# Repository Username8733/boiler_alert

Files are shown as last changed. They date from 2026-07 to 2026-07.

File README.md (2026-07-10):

# ESPHome Boiler Monitor






An ESPHome-based optical alarm monitor for boilers and other equipment with a visible warning LED.

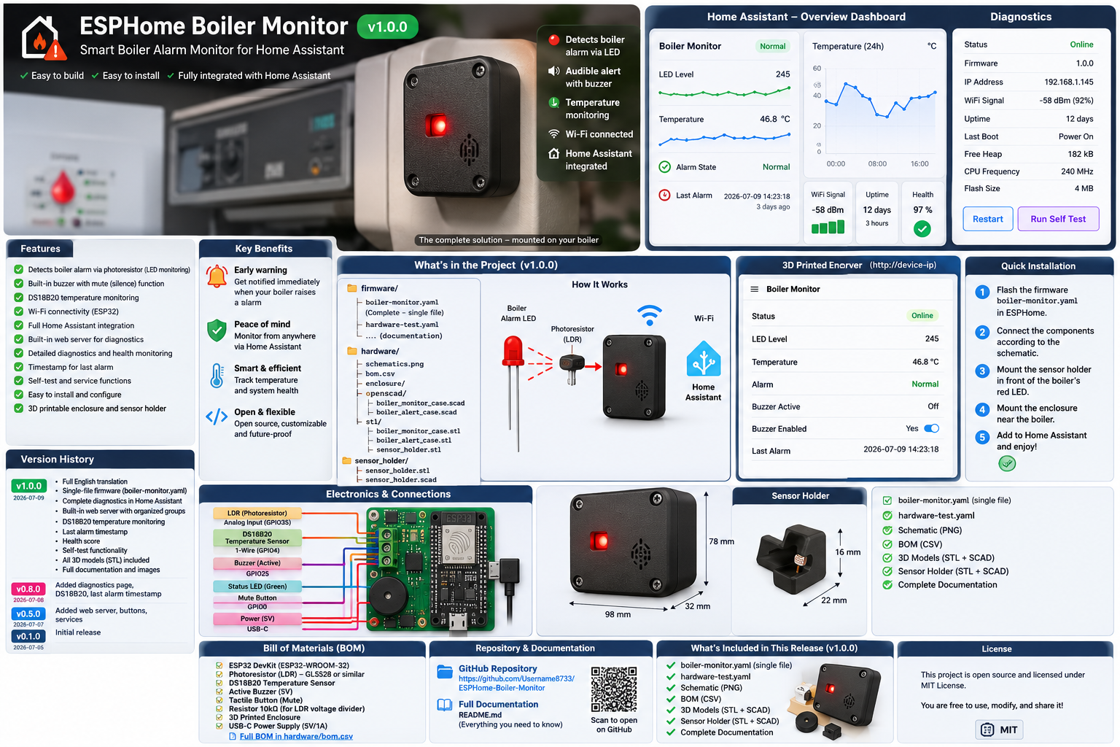
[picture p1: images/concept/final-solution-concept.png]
Final solution concept


## Features

- Optical alarm detection using a phototransistor
- Adjustable threshold
- Local red alarm LED
- Green status LED
- Active 5 V buzzer through a 2N7000 MOSFET
- Physical mute button
- DS18B20 temperature sensor support
- Last-alarm timestamp
- Built-in ESPHome web interface
- Home Assistant overview and diagnostics dashboards
- Dedicated hardware-test firmware
- 3D-printable enclosure and sensor holder

## Repository structure

```text
firmware/
  boiler-monitor.yaml
  hardware-test.yaml
  secrets.yaml.example

hardware/
  bom/
  wiring/
  enclosure/
    stl/
    openscad/

docs/
  Installation.md
  Hardware-Test.md
  Calibration.md
  Diagnostics.md
  Enclosure.md
  Troubleshooting.md

homeassistant/
  overview.yaml
  diagnostics.yaml
  notifications.yaml

images/
  concept/
  functions/
```

## Quick start

1. Copy `firmware/secrets.yaml.example` values into your ESPHome `secrets.yaml`.
2. Flash `firmware/hardware-test.yaml`.
3. Verify the LEDs, buzzer, MOSFET driver, and button.
4. Build the remaining circuit using `hardware/wiring/CONNECTION_TABLE.md`.
5. Flash `firmware/boiler-monitor.yaml`.
6. Add the ESPHome device to Home Assistant.
7. Import the Home Assistant dashboard files.
8. Calibrate the optical sensor.

## GPIO mapping

| Function | GPIO |
|---|---:|
| Phototransistor analog input | GPIO34 |
| Buzzer MOSFET gate | GPIO18 |
| Red alarm LED | GPIO19 |
| Green status LED | GPIO21 |
| Mute button | GPIO22 |
| DS18B20 data | GPIO23 |

## Wiring illustrations

- [Power](images/functions/01_power.png)
- [Phototransistor sensor](images/functions/02_phototransistor_sensor.png)
- [Red alarm LED](images/functions/03_red_alarm_led.png)
- [Green status LED](images/functions/04_green_status_led.png)
- [2N7000 and buzzer](images/functions/05_mosfet_buzzer.png)
- [Mute button](images/functions/06_mute_button.png)
- [DS18B20](images/functions/07_ds18b20.png)

SVG source files are included next to the PNG images.

## Firmware

Use one of these files:

- `firmware/hardware-test.yaml` for initial hardware verification
- `firmware/boiler-monitor.yaml` for normal operation

Both are standalone ESPHome files.

## Home Assistant

- `homeassistant/overview.yaml`
- `homeassistant/diagnostics.yaml`
- `homeassistant/notifications.yaml`

When Home Assistant and the ESP32 are on different VLANs, add the ESPHome integration manually using the device IP address.

## 3D-printable files

STL and OpenSCAD files are included for:

- Boiler Alert case
- Boiler Monitor case
- Optical sensor holder

## Documentation

- [Installation](docs/Installation.md)
- [Hardware test](docs/Hardware-Test.md)
- [Calibration](docs/Calibration.md)
- [Diagnostics](docs/Diagnostics.md)
- [Enclosure](docs/Enclosure.md)
- [Troubleshooting](docs/Troubleshooting.md)

## External links

- [ESPHome](https://esphome.io/)
- [Home Assistant](https://www.home-assistant.io/)
- [ESPHome integration](https://www.home-assistant.io/integrations/esphome/)
- [Project repository](https://github.com/Username8733/ESPHome-Boiler-Monitor)

## Safety

This is a hobby monitoring accessory. It does not replace the boiler manufacturer's safety systems, alarms, inspections, or maintenance requirements.

## License

MIT. See [LICENSE](LICENSE).

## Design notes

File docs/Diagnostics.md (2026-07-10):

# Diagnostics

The built-in ESPHome web server and Home Assistant diagnostics page expose:

- Firmware version
- IP address, SSID, MAC address
- Wi-Fi RSSI and calculated percentage
- Uptime
- LED level and threshold
- Boiler LED detected
- Latched alarm
- Buzzer active, muted, and enabled
- DS18B20 temperature
- Last alarm timestamp
- Hardware test, buzzer test, and restart controls

When Home Assistant and the ESP32 are on different VLANs, add the ESPHome integration manually by IP address and allow TCP 6053.

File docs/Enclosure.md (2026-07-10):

# Enclosure and Sensor Holder

Included models:

- `boiler_alert_case.scad` / `.stl`
- `boiler_monitor_case.scad` / `.stl`
- `sensor_holder.scad` / `.stl`

Recommended print settings:

- Black PETG or PLA
- 0.2 mm layer height
- 20-40% infill
- Print the sensor holder in black to reduce ambient-light leakage

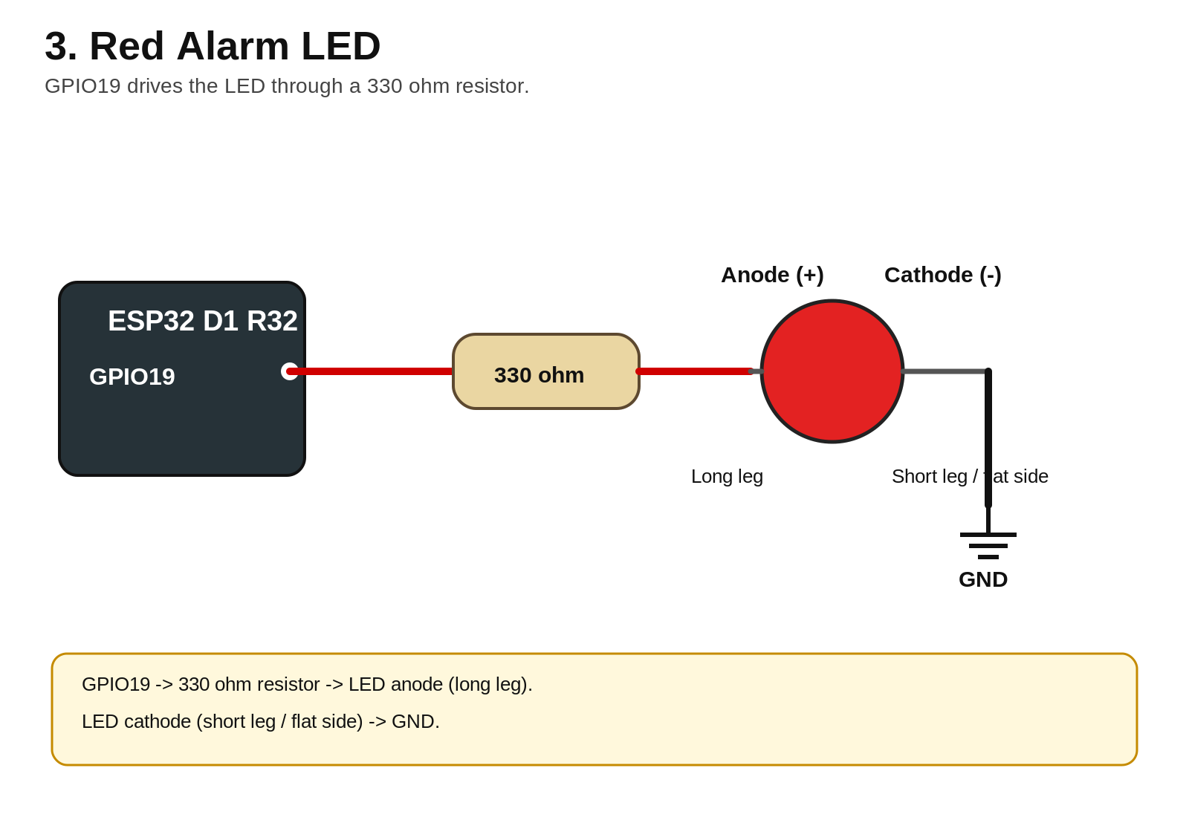
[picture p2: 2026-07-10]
images/functions/03_red_alarm_led.png

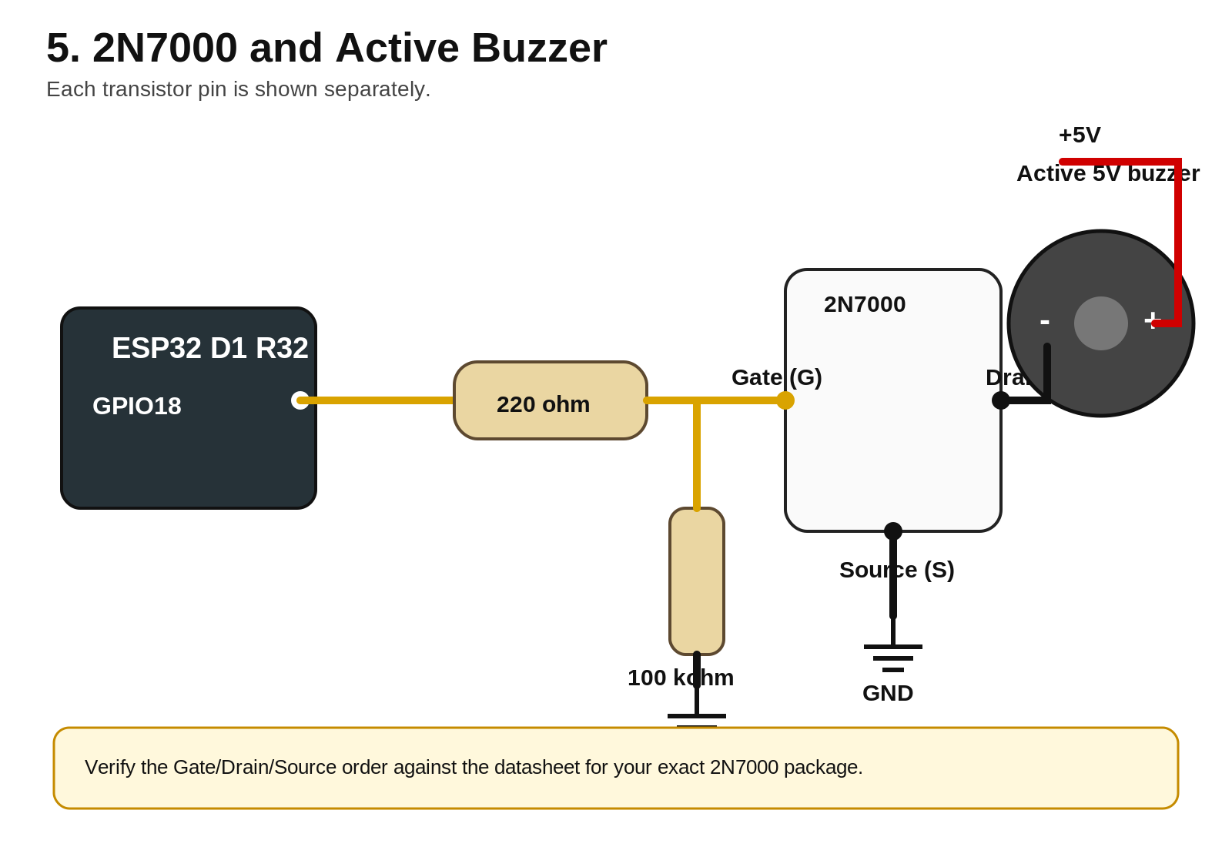
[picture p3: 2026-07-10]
images/functions/05_mosfet_buzzer.png

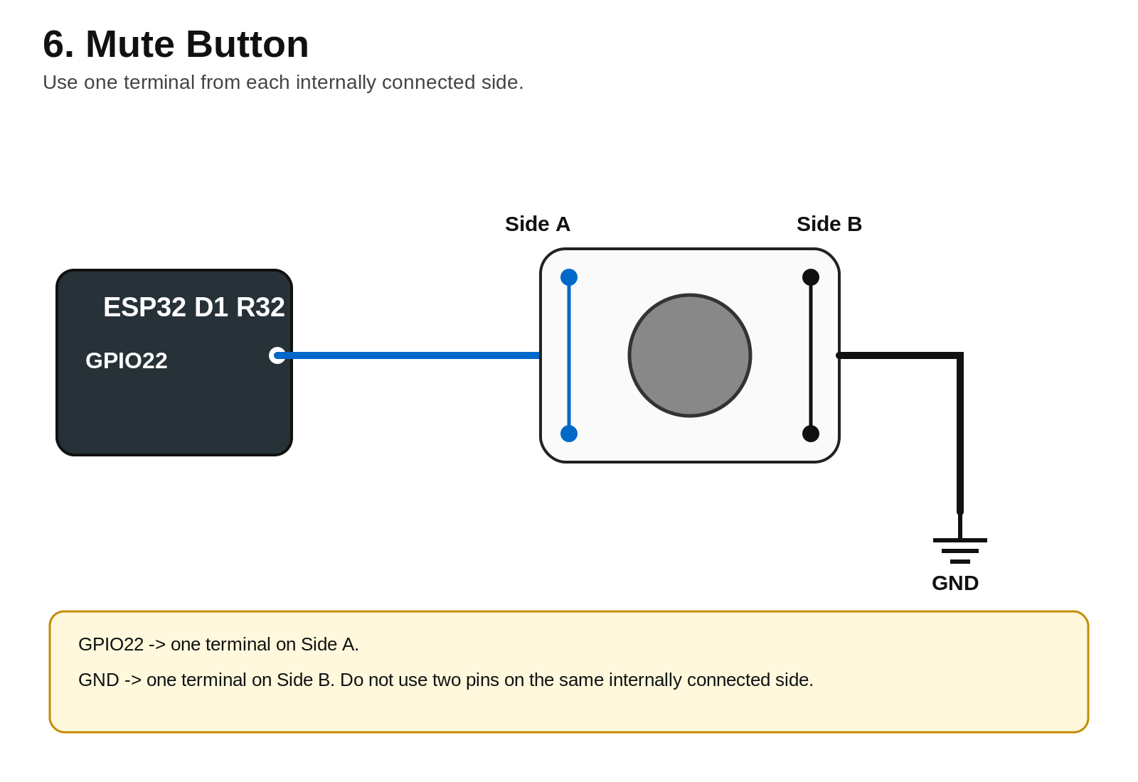
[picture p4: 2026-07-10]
images/functions/06_mute_button.png

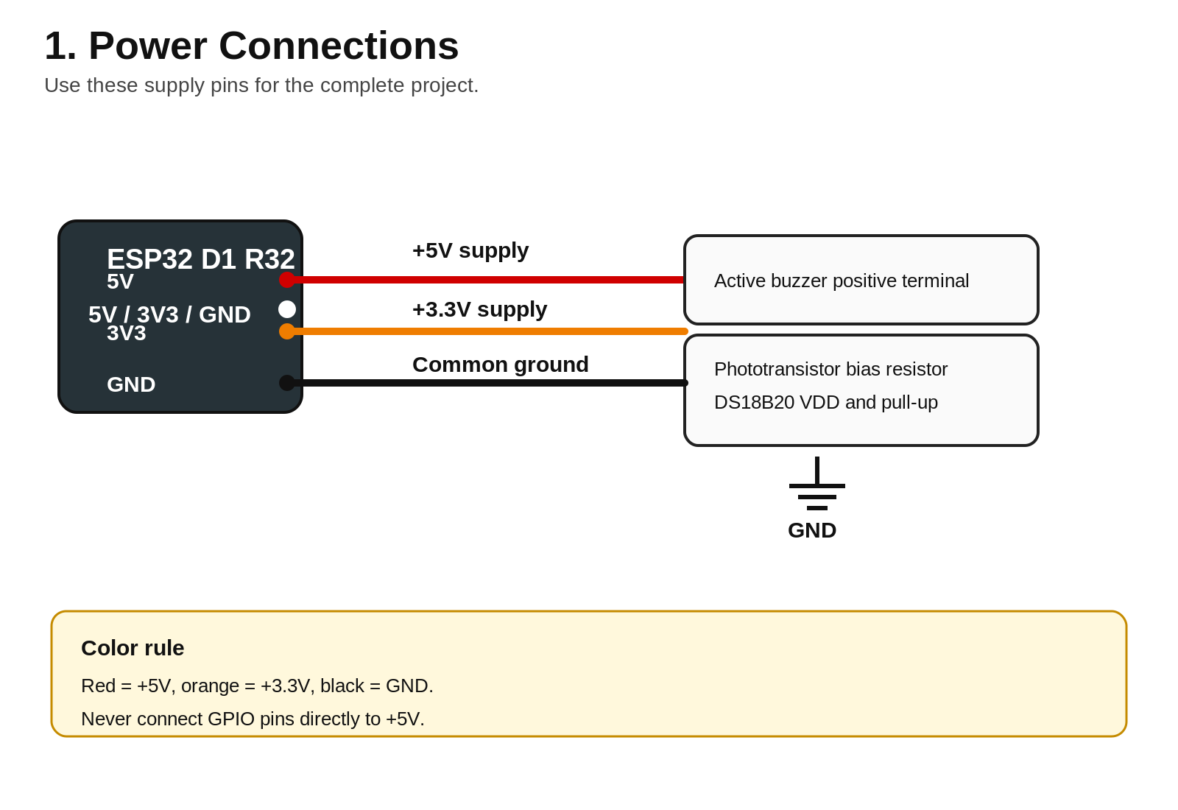
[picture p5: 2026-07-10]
images/functions/01_power.png

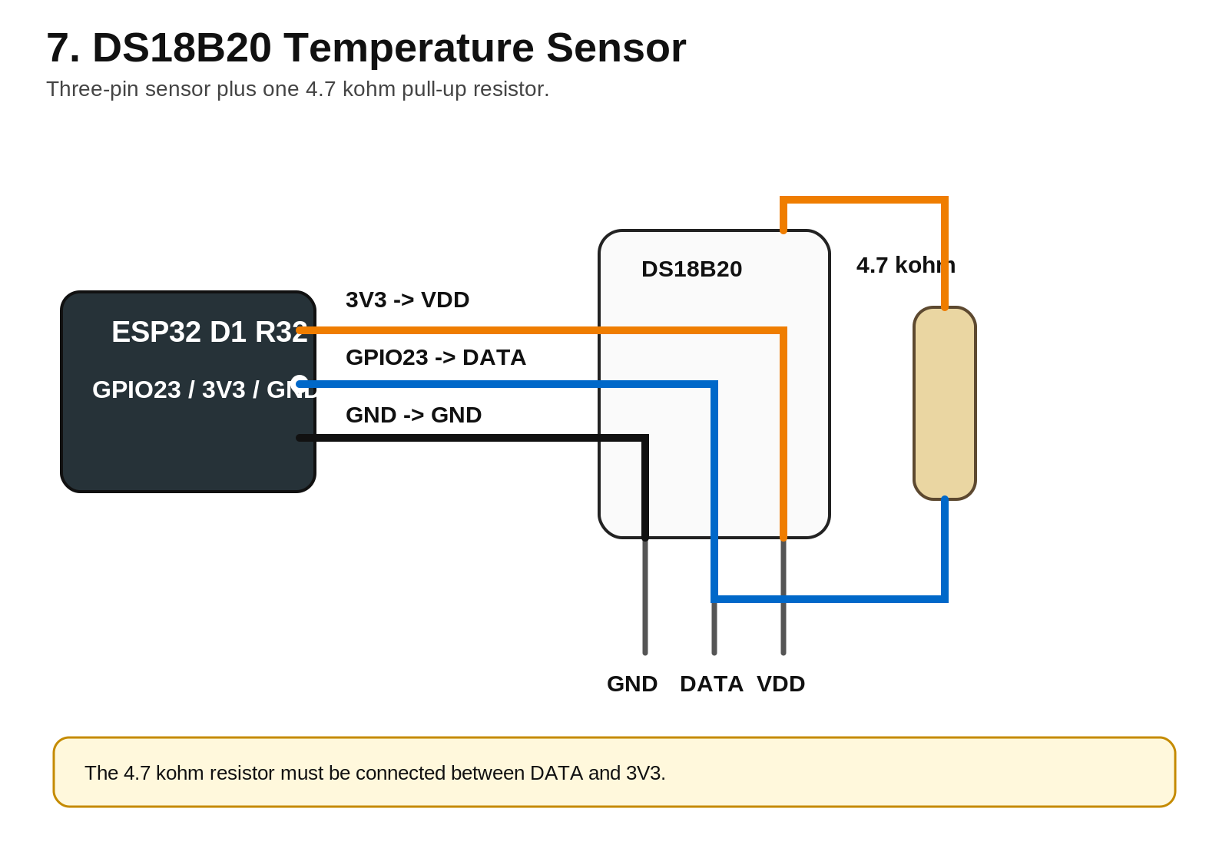
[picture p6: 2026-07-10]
images/functions/07_ds18b20.png

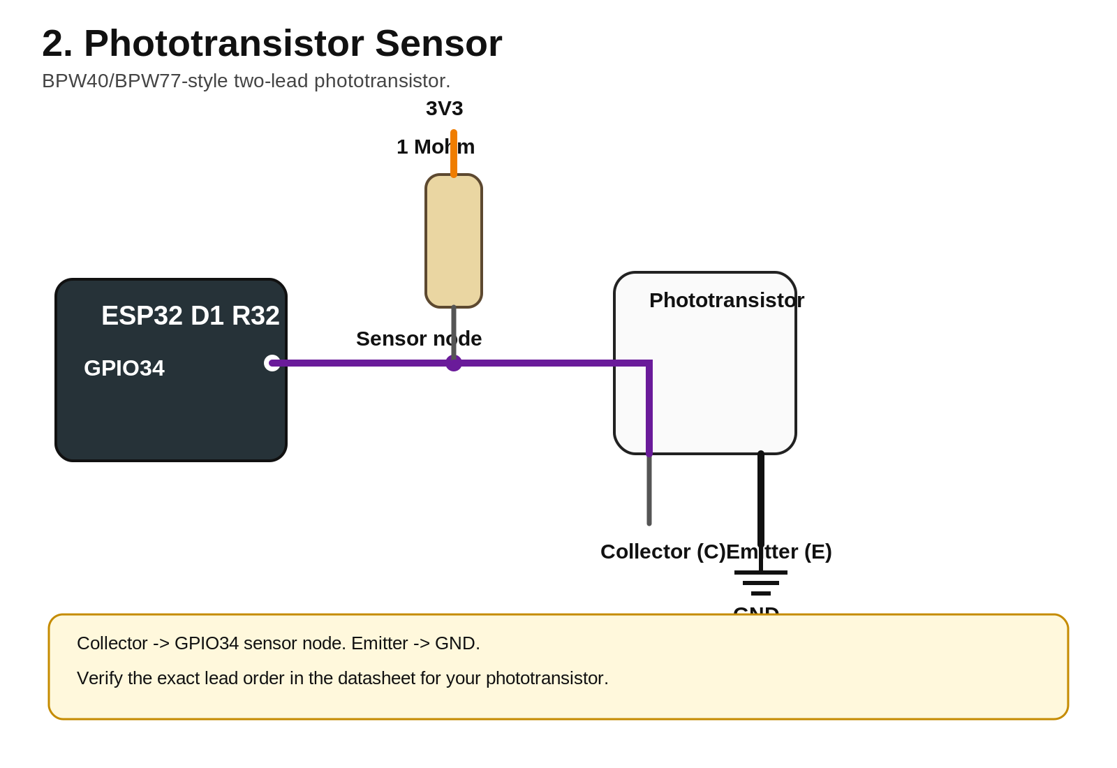
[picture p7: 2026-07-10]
images/functions/02_phototransistor_sensor.png

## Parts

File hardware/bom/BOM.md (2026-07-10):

# Bill of Materials

| Qty | Ref | Part | Value / Type | Purpose |
|---:|---|---|---|---|
| 1 | U1 | ESP32 D1 R32 / ESP32 UNO |  | Controller |
| 1 | Q2 | Phototransistor | BPW40/BPW77 or similar | Optical LED sensor |
| 1 | Q1 | N-channel MOSFET | 2N7000 | Buzzer low-side driver |
| 1 | B1 | Active buzzer | 5 V | Local audible alarm |
| 1 | LED1 | Red LED | 5 mm | Mirrors boiler alarm LED |
| 1 | LED2 | Green LED | 5 mm | Run/status indication |
| 1 | SW1 | Momentary pushbutton | Normally open | Mute/acknowledge |
| 2 | R_LED | Resistor | 330 ohm | LED current limiting |
| 1 | R_GATE | Resistor | 220 ohm | MOSFET gate resistor |
| 1 | R_PD | Resistor | 100 kohm | MOSFET gate pulldown |
| 1 | R_SENSOR | Resistor | 1 Mohm | Phototransistor bias |
| 1 | T1 | DS18B20 | 1-Wire | Temperature sensor |
| 1 | R_TEMP | Resistor | 4.7 kohm | DS18B20 pull-up |
| 1 | C1 | Capacitor | 100 nF | Optional sensor filtering |
| 1 | BOARD | Breadboard/perfboard | 2.54 mm | Prototype assembly |

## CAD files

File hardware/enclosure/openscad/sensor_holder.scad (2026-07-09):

// ESPHome Boiler Monitor sensor holder for BPW40/BPW77 phototransistor
$fn = 64;
outer_d = 10;
inner_d = 5;
length = 18;

difference() {
  cylinder(h=length, d=outer_d);
  translate([0,0,-1]) cylinder(h=length+2, d=inner_d);
}

translate([-10,-5,0])
  cube([20,10,2]);

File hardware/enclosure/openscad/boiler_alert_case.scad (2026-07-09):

// Boiler Alert enclosure - printable concept
$fn = 48;
box_w = 100; box_h = 60; box_d = 30; wall = 2;

module base_box() {
  difference() {
    cube([box_w, box_h, box_d]);
    translate([wall, wall, wall]) cube([box_w-2*wall, box_h-2*wall, box_d]);
  }
}

module lid() {
  difference() {
    cube([box_w, box_h, 3]);
    translate([15, 15, -1]) cylinder(h=6, d=5);   // red LED
    translate([30, 15, -1]) cylinder(h=6, d=5);   // green LED
    translate([50, 15, -1]) cylinder(h=6, d=12);  // buzzer
    translate([75, 15, -1]) cylinder(h=6, d=7);   // mute
  }
}

base_box();
translate([0, 70, 0]) lid();

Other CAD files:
hardware/enclosure/openscad/boiler_monitor_case.scad

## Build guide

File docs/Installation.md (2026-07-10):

# Installation

## ESPHome Builder

1. Copy `firmware/release/boiler-monitor.yaml` into the ESPHome configuration directory.
2. Copy the required values from `firmware/release/secrets.yaml.example` into your ESPHome `secrets.yaml`.
3. Open the YAML file in ESPHome Builder.
4. Select **Install** and compile the firmware.
5. Flash by USB for the first installation. Later updates can use OTA.

The single-file release does not require the `packages` directory.

## Home Assistant

If automatic discovery works, approve the discovered ESPHome device.

When Home Assistant and the ESP32 are on different VLANs:

1. Open **Settings > Devices & services**.
2. Add the **ESPHome** integration manually.
3. Enter the ESP32 IP address.
4. Allow TCP 6053 from Home Assistant to the IoT VLAN.

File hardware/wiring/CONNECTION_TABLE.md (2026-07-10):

# Connection Table

| ID | Color | From | To | Function |
|---|---|---|---|---|
| W01 | Red | ESP32 5V | +5V rail | Power |
| W02 | Black | ESP32 GND | GND rail | Common ground |
| W03 | Orange | ESP32 3V3 | 1 Mohm resistor | Sensor bias |
| W04 | Purple | Sensor node | ESP32 GPIO34 | Analog input |
| W05 | Black | Phototransistor emitter | GND | Sensor ground |
| W06 | Purple | Phototransistor collector | GPIO34 node | Sensor signal |
| W07 | Red signal | ESP32 GPIO19 | 330 ohm resistor | Red LED |
| W08 | Black | Red LED cathode | GND | Red LED ground |
| W09 | Green | ESP32 GPIO21 | 330 ohm resistor | Green LED |
| W10 | Black | Green LED cathode | GND | Green LED ground |
| W11 | Yellow | ESP32 GPIO18 | 220 ohm resistor | MOSFET gate |
| W12 | Yellow | 220 ohm resistor | 2N7000 gate | Buzzer control |
| W13 | Black | Gate via 100 kohm | GND | Gate pulldown |
| W14 | Red | +5V | Buzzer + | Buzzer supply |
| W15 | Black | Buzzer - | 2N7000 drain | Switched ground |
| W16 | Black | 2N7000 source | GND | MOSFET ground |
| W17 | Blue | ESP32 GPIO22 | Pushbutton | Mute input |
| W18 | Black | Pushbutton | GND | Mute ground |
| W19 | Orange | ESP32 3V3 | DS18B20 VDD | Temperature supply |
| W20 | Black | ESP32 GND | DS18B20 GND | Temperature ground |
| W21 | Brown | ESP32 GPIO23 | DS18B20 DATA | 1-Wire data |
| W22 | Orange | DS18B20 DATA | 4.7 kohm to 3V3 | 1-Wire pull-up |

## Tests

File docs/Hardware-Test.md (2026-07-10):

# Hardware Test

Flash `firmware/release/hardware-test.yaml` before connecting the optical sensor.

## Startup sequence

1. Green LED turns on briefly.
2. Red LED turns on briefly.
3. Buzzer sounds briefly.
4. Green LED remains on.

## Button test

Pressing the physical button:

- turns off the green LED,
- sounds the buzzer for one second,
- keeps the red LED on for three seconds total,
- then returns to the green status LED.

This verifies GPIO18, GPIO19, GPIO21, GPIO22, the LEDs, the buzzer driver, and the button.

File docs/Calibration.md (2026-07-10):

# Calibration

1. Read `Boiler Monitor LED Level` while the boiler LED is off.
2. Read it again while the boiler LED is on.
3. Set `LED Threshold` approximately halfway between the two readings.
4. Confirm `Boiler LED Detected` only changes to ON when the boiler alarm LED is lit.
5. Shield the sensor from ambient light using the printed holder or black heat-shrink tubing.

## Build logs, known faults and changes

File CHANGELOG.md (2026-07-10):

# Changelog

## v2.0.0-rc4

- Removed GitHub workflows and project-maintenance files
- Removed internal audit and checksum files
- Removed modular development firmware
- Flattened firmware and Home Assistant directories
- Removed individual PDF versions of function diagrams
- Removed the combined PDF manual for now
- Kept PNG and SVG wiring illustrations
- Kept all STL and OpenSCAD files
- Simplified documentation structure
- Updated README to match the simplified repository

## v2.0.0-rc3

- Restored visual wiring illustrations
- Added explicit component-pin labels
- Added SVG source files

## Earlier versions

See the Git history for the complete development history.

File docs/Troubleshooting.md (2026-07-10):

# Troubleshooting

## Device is visible in ESPHome Builder but not Home Assistant

Automatic discovery may not cross VLAN boundaries. Add the ESPHome integration manually using the device IP address.

## Red alarm LED is always on

- Increase the LED threshold.
- Block ambient light from reaching the phototransistor.
- Verify the phototransistor orientation.

## Boiler LED is never detected

- Lower the LED threshold.
- Check GPIO34 wiring.
- Verify the 1 Mohm sensor resistor.
- Reverse the phototransistor if the signal moves in the wrong direction.

## Buzzer does not sound

- Run the hardware-test firmware.
- Verify the active buzzer polarity.
- Verify the 2N7000 gate, drain, and source using its exact datasheet.
- Confirm the buzzer is rated for 5 V.

## DS18B20 is missing

- Verify DATA is connected to GPIO23.
- Add 4.7 kohm between DATA and 3V3.
- Check VDD and GND.

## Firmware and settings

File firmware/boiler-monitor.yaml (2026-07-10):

substitutions:
  device_name: boiler-monitor
  friendly_name: Boiler Monitor
  firmware_version: "2.0.0-rc4"

esphome:
  name: ${device_name}
  friendly_name: ${friendly_name}
  project:
    name: username8733.esphome-boiler-monitor
    version: ${firmware_version}

  on_boot:
    priority: -100
    then:
      # Simple startup indication:
      # green LED on, red LED briefly on, short buzzer beep, green LED on.
      - output.turn_on: green_led_output
      - delay: 250ms
      - output.turn_on: red_led_output
      - delay: 250ms
      - output.turn_off: red_led_output
      - if:
          condition:
            switch.is_on: buzzer_enabled
          then:
            - output.turn_on: buzzer_output
            - delay: 120ms
            - output.turn_off: buzzer_output
      - output.turn_on: green_led_output

esp32:
  board: esp32dev
  framework:
    type: arduino

logger:

api:
  reboot_timeout: 15min

ota:
  platform: esphome

wifi:
  ssid: !secret wifi_ssid
  password: !secret wifi_password

  ap:
    ssid: "${friendly_name} Fallback"
    password: !secret fallback_ap_password

captive_portal:

web_server:
  port: 80

time:
  - platform: homeassistant
    id: ha_time

########################################################
# Outputs
########################################################

output:
  - platform: gpio
    pin: GPIO18
    id: buzzer_output

  - platform: gpio
    pin: GPIO19
    id: red_led_output

  - platform: gpio
    pin: GPIO21
    id: green_led_output

########################################################
# Diagnostic text sensors
########################################################

text_sensor:
  - platform: template
    name: "${friendly_name} Firmware Version"
    icon: mdi:tag
    entity_category: diagnostic
    lambda: |-
      return std::string("${firmware_version}");

  - platform: template
    name: "${friendly_name} Last Alarm"
    id: last_alarm_text
    icon: mdi:clock-alert
    update_interval: never

  - platform: wifi_info
    ip_address:
      name: "${friendly_name} IP Address"
      entity_category: diagnostic
    ssid:
      name: "${friendly_name} Connected SSID"
      entity_category: diagnostic
    mac_address:
      name: "${friendly_name} MAC Address"
      entity_category: diagnostic

########################################################
# Sensors
########################################################

sensor:
  # Raw light level from the phototransistor
  - platform: adc
    pin: GPIO34
    id: boiler_led_level
    name: "${friendly_name} LED Level"
    attenuation: 11db
    update_interval: 100ms
    accuracy_decimals: 3
    filters:
      - exponential_moving_average:
          alpha: 0.25
          send_every: 1

  # WiFi RSSI
  - platform: wifi_signal
    id: wifi_rssi
    name: "${friendly_name} WiFi Signal"
    update_interval: 60s
    entity_category: diagnostic

  # Wi-Fi quality as a percentage
  - platform: copy
    source_id: wifi_rssi
    name: "${friendly_name} WiFi Signal Percent"
    unit_of_measurement: "%"
    entity_category: diagnostic
    filters:
      - lambda: |-
          if (x <= -100.0) return 0.0;
          if (x >= -50.0) return 100.0;
          return 2.0 * (x + 100.0);

  # Uptime
  - platform: uptime
    name: "${friendly_name} Uptime"
    update_interval: 60s
    entity_category: diagnostic

  # DS18B20 temperature sensor
  # Wiring:
  # VDD  -> 3V3
  # GND  -> GND
  # DATA -> GPIO23
  # 4.7k between DATA and 3V3
  - platform: dallas_temp
    name: "${friendly_name} Temperature"
    id: boiler_temperature
    update_interval: 30s
    accuracy_decimals: 1

########################################################
# 1-Wire bus for DS18B20
########################################################

one_wire:
  - platform: gpio
    pin: GPIO23
    id: one_wire_bus

########################################################
# Adjustable settings
########################################################

number:
  - platform: template
    id: boiler_led_threshold
    name: "${friendly_name} LED Threshold"
    optimistic: true
    restore_value: true
    initial_value: 1.20
    min_value: 0.05
    max_value: 3.10
    step: 0.05
    unit_of_measurement: "V"

  - platform: template
    id: alarm_clear_delay_seconds
    name: "${friendly_name} Alarm Clear Delay"
    optimistic: true
    restore_value: true
    initial_value: 0
    min_value: 0
    max_value: 600
    step: 10
    unit_of_measurement: "s"

########################################################
# Globals
########################################################

globals:
  - id: alarm_latched
    type: bool
    restore_value: no
    initial_value: 'false'

  - id: alarm_muted
    type: bool
    restore_value: no
    initial_value: 'false'

  - id: buzzer_phase
    type: bool
    restore_value: no
    initial_value: 'false'

  - id: last_alarm_seen_ms
    type: uint32_t
    restore_value: no
    initial_value: '0'
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

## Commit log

2026-07-09 Initial Boiler Alert project
    [BOM.csv, boiler_alert_case.scad, sensor_holder.scad]
2026-07-09 v 0.2.0
    [boiler_monitor_case.scad, sensor_holder.scad]
2026-07-09 v 0.4.0
    [sensor_holder.scad]
2026-07-09 v 0.5.0
    [BOM.csv, sensor_holder.scad]
2026-07-09 v 0.6.0
    [BOM.csv]
2026-07-09 hardware-test firmware
    [hardware-test.yaml]
2026-07-09 v 0.8.0
    [BOM.csv]
2026-07-10 v2.0 eng
    [hardware-test.yaml, sensor_holder-old.scad]
2026-07-10 Simplify project structure for v2.0.0-rc4
    [BOM.csv, hardware-test.yaml]
